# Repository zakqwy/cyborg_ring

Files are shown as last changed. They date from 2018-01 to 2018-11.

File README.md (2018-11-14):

# cyborg ring
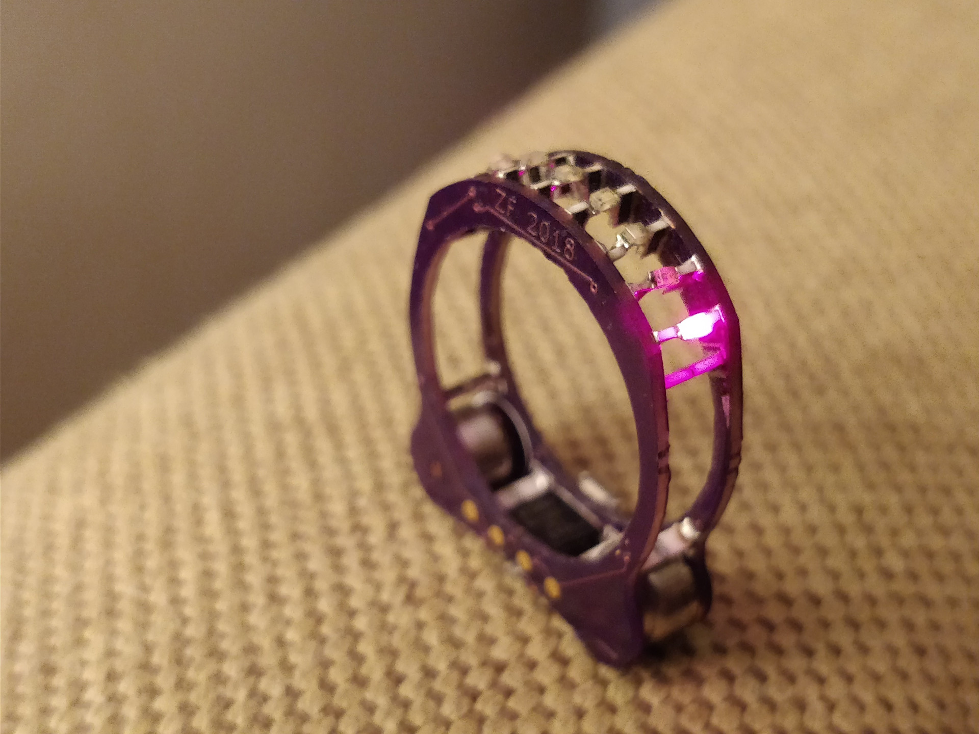
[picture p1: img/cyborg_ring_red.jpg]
cyborg ring with red LEDs

cyborg ring is a cordwood-style bit of blinky jewelry powered by an ATtiny85 and a pair of size 10 Zn-air (hearing aide) batteries. The latest iteration includes several tension wires as well as other minor updates and has proven its durability to be sufficient to warrant a beta release. Note that this ring is difficult to make, still quite delicate, not waterproof (even if you conformal coat most of it), and somewhat uncomfortable. But it's also quite unique.
## license
cyborg ring is released under the terms of the Creative Commons Attribution-ShareAlike 4.0 license, available here: http://creativecommons.org/licenses/by-sa/4.0/.


The project recently received certification from the Open Source Hardware Association, US000141.
OSHWA Certification
## project status
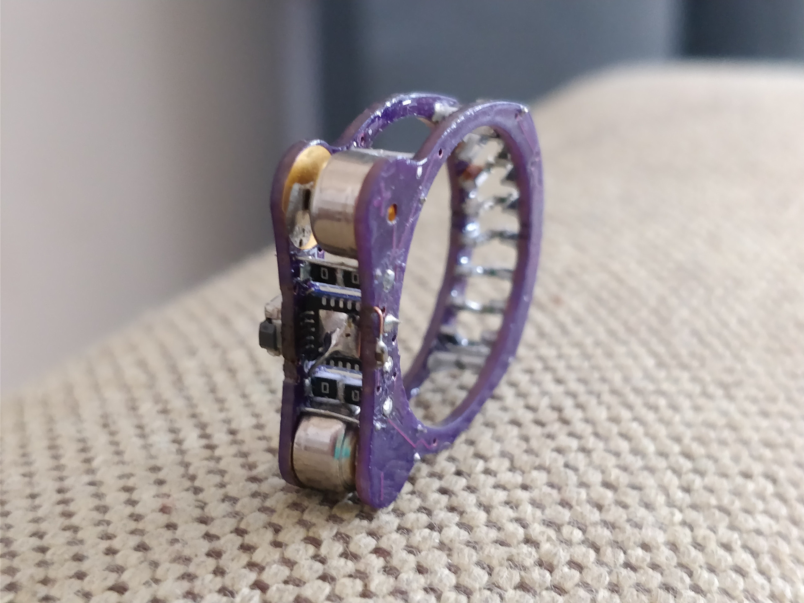
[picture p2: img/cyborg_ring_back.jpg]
cyborg ring rear view

The ring works and seems to last at least a few weeks without breaking; having said that, the ring is still delicate and should be treated like a beta-release concept still in need of some polishing. By popular demand, I'll probably put together a CrowdSupply campaign for kits that will include good instructions, pre-programmed microcontrollers, and LED color / ring size choice. On the subject of size, this version is nominally equivalent to ring size 9. Practically, it's better as a 7 or 8 as the bare FR4 is a bit rough when worn too tight.
## build instructions
I did a live stream in October 2018 that shows a complete ring build start-to-finish. You can view an unedited recording of the stream [here](https://youtu.be/spNg8LhxJz0). I also made a brief video that just goes over the tools and materials, available [here](https://youtu.be/D9dDy7vboAA). These are both great starting points if you are new to the project.
### step zero: prepare thyself
This is a fun and challenging project. Building a ring can be frustrating, especially if you aren't used to working with tiny parts, but if you take your time it is eminently possible even if you are fairly new to soldering. Make sure you are comfortable, not overly caffeinated (as shaky hands make it quite tough), and try to avoid interruptions for the next few hours. Remember that you have extra parts, and even if you damage a PCB the replacements are quite cheap (although they may take a week or two to arrive in the mail).
### step one: source PCBs
Use a service like [OSHpark](https://oshpark.com/shared_projects/sZ3MaKA4) (or any other high-quality PCB vendor) to fabricate the boards. They should be routed with mousebites, 0.8mm (1/32") FR4, ENIG, double-sided. Note that some traces are a bit close to the PCB edge so you may need to try a few services or have your bodge wires handy:
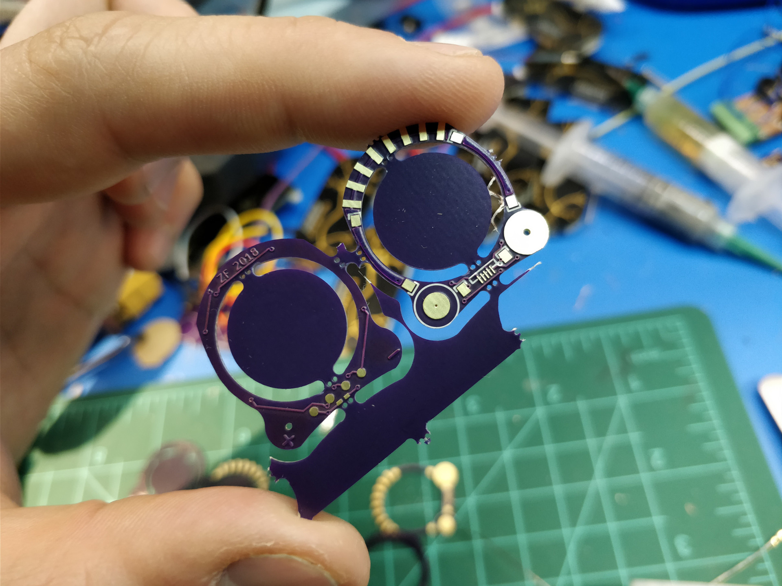
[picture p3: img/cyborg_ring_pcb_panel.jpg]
cyborg ring pcb panel


If necessary, _carefully_ sand down the mouse bites after removing excess FR4. Make sure to wear suitable PPE (safety glasses, a dust mask, etc) and clean up when you are finished:
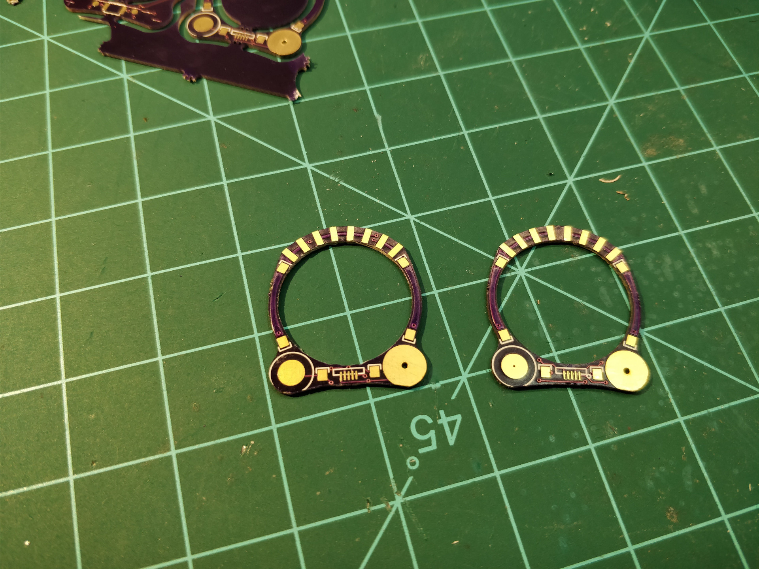
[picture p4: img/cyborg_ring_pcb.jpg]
cyborg ring pcb

### step two: source all the parts
I did a short run of kits that were given away at the 2018 Supercon; if you got one, you already have all you need beyond the tools listed:
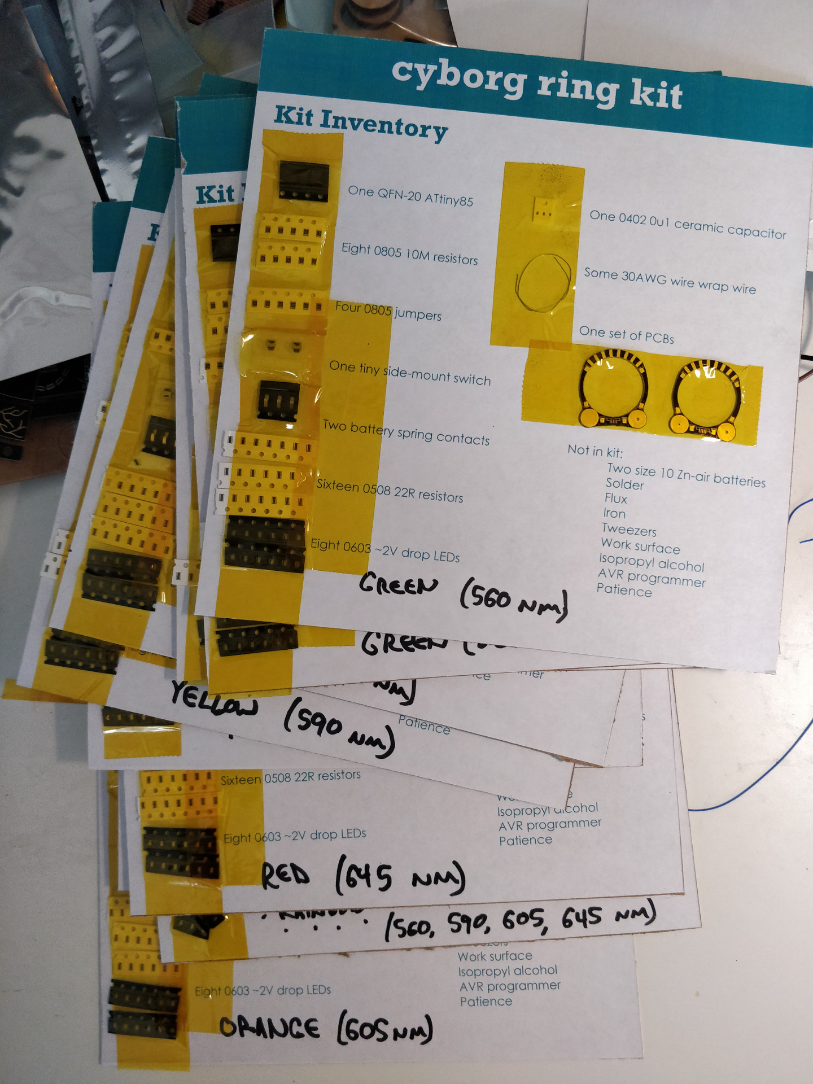
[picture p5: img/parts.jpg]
parts


Otherwise, order the parts listed in bom.csv in the HARDWARE directory. I usually get parts from Digi-Key, but most large electronics distributors should have the parts. Make sure you buy 0508 resistors for the LEDs; they're a bit funky and substantially less common than 0805 devices (which you also need). And don't even _think_ about not ordering sufficient spares of _everything_.
### step three: assemble the resistor columns
You need six columns altogether. Four should be constructed from a pair of 10M 0805 resistors, marked '106', to give a total resistance of 20M. Two should be constructed from a pair of 0805 jumpers, marked '0'. To fabricate the columns, position the two resistors next to each other on a heat-resistant surface (such as a Teflon-jawed Stickvise):
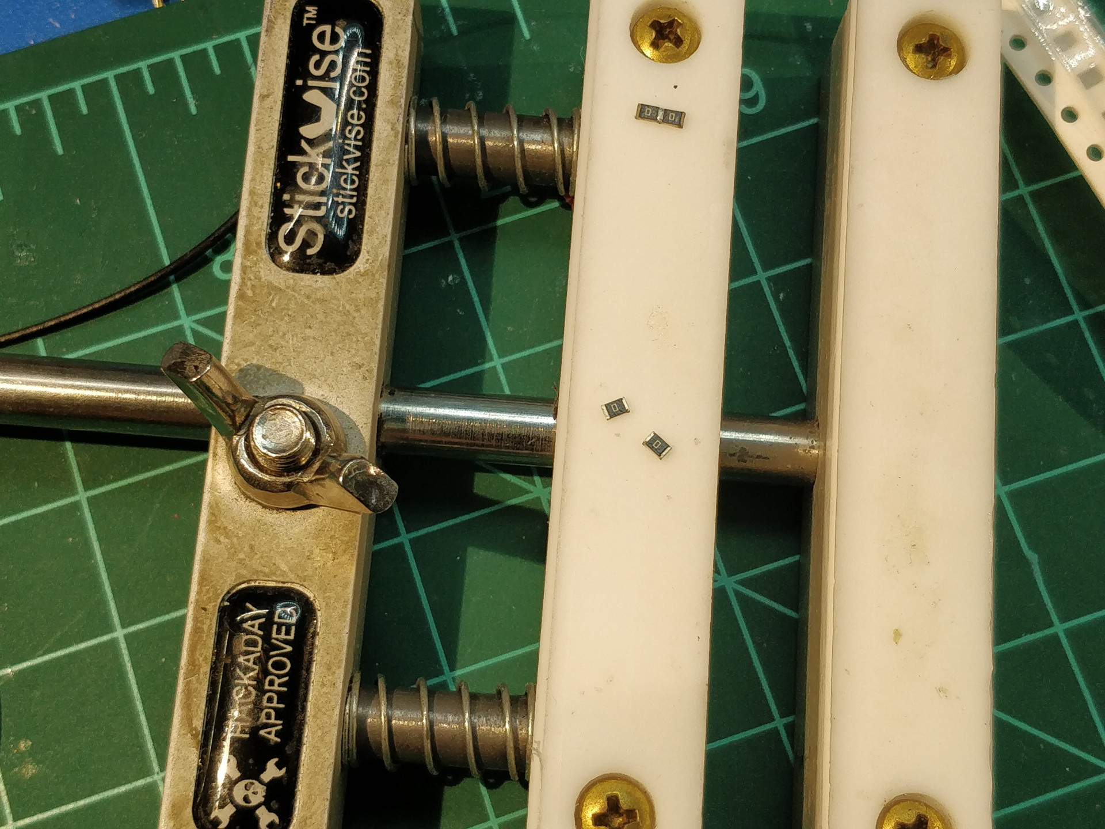
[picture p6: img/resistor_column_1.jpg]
resistor column 1


Squeeze the two resistors together with a pair of tweezers. Make sure they are square to each other and don't squeeze so hard the resistors buckle up in the center; the column should be flat but firmly held:
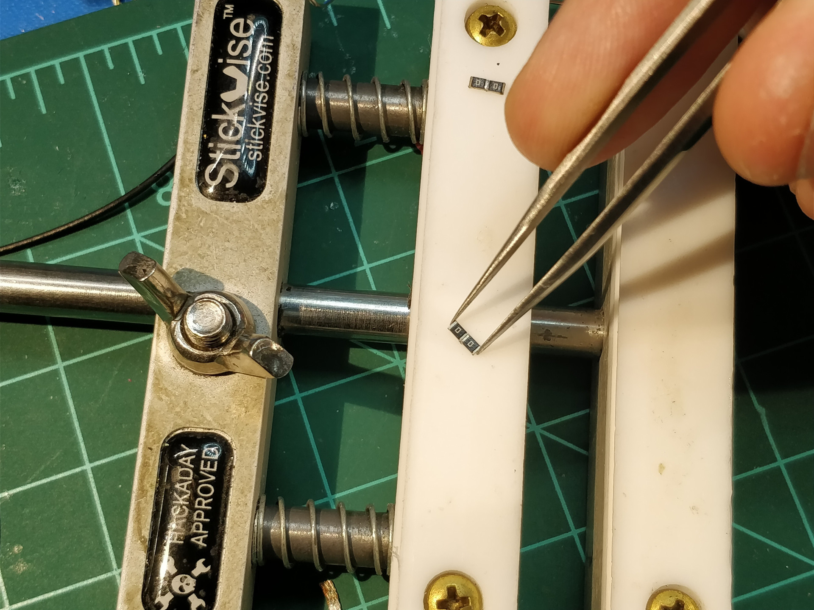
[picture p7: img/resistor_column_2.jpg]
resistor column 2


Apply a bit of gel flux to the junction:
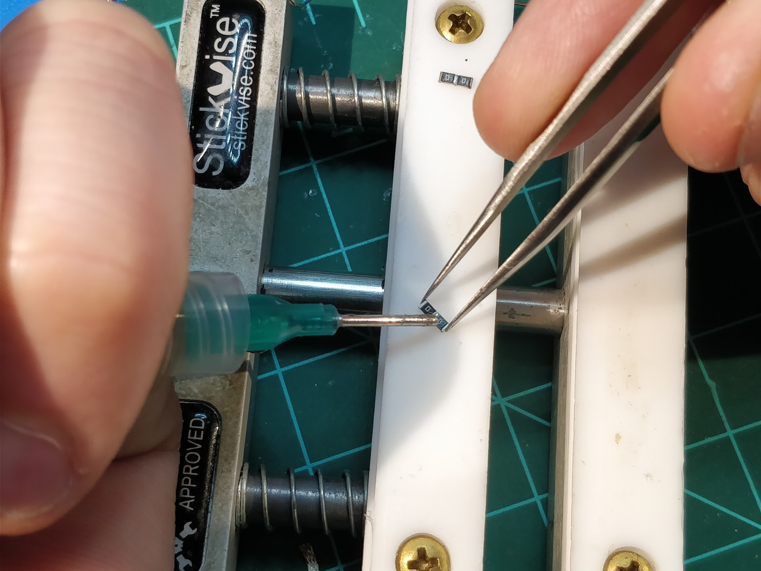
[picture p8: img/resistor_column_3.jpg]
resistor column 3


Touch your tinned soldering iron to the junction, allowing a bit of solder to flow around the joint:
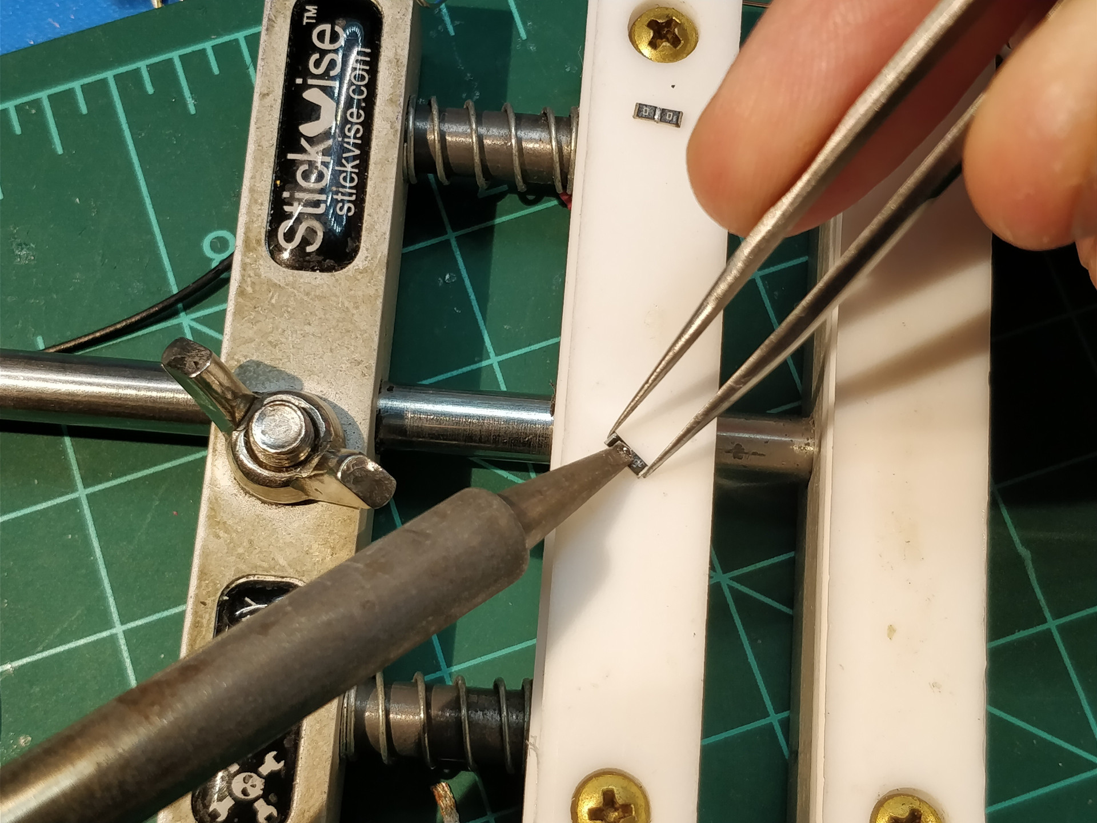
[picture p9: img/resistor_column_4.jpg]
resistor column 4


The finished product should be straight and square, as seen here:
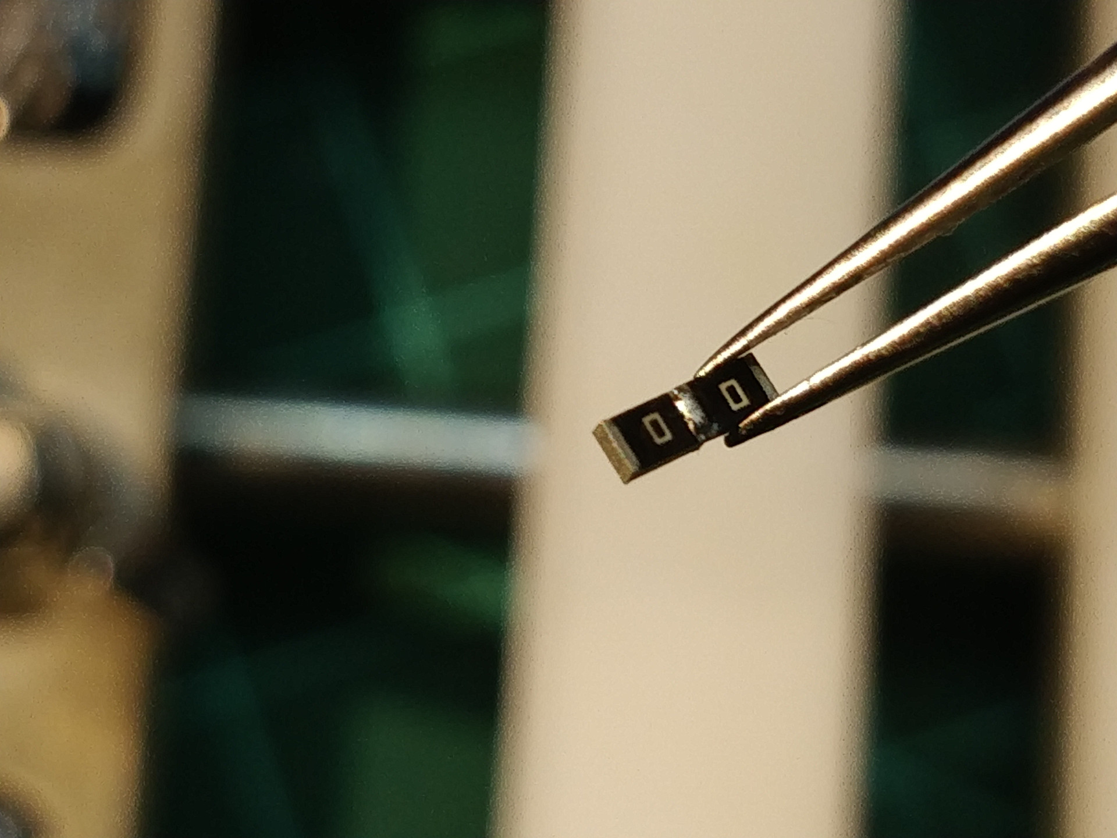
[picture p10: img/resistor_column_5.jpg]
resistor column 5


Repeat as needed until you have two jumper columns and four structural (10M + 10M) columns.
### step four: solder parts to individual ring halves
Identify the bottom half of the ring. This half has two round pads on the back, along with two rectangular pads for the switch. On the front, the ATtiny85 silkscreen has a tiny circle to indicate the location of Pin 1. It also says "cyborg ring" opposite the LEDs:
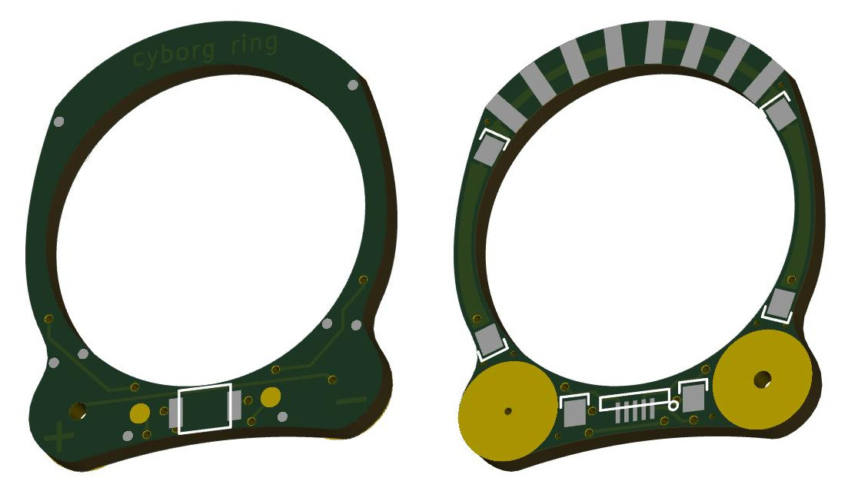
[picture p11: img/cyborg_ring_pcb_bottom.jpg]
cyborg ring pcb bottom


Start by soldering the QFN ATtiny85 to the PCB. You should carefully mount the board in a vise of some kind, or tape it to a work surface (such as an old bit of wood) so it doesn't move around. Use tweezers to orient the QFN so its ground pad faces the bottom part of the ring, and the outline lines up with the white silkscreen square. Be sure the notch on the ground pad, which indicates pin 1, is down and to the right:
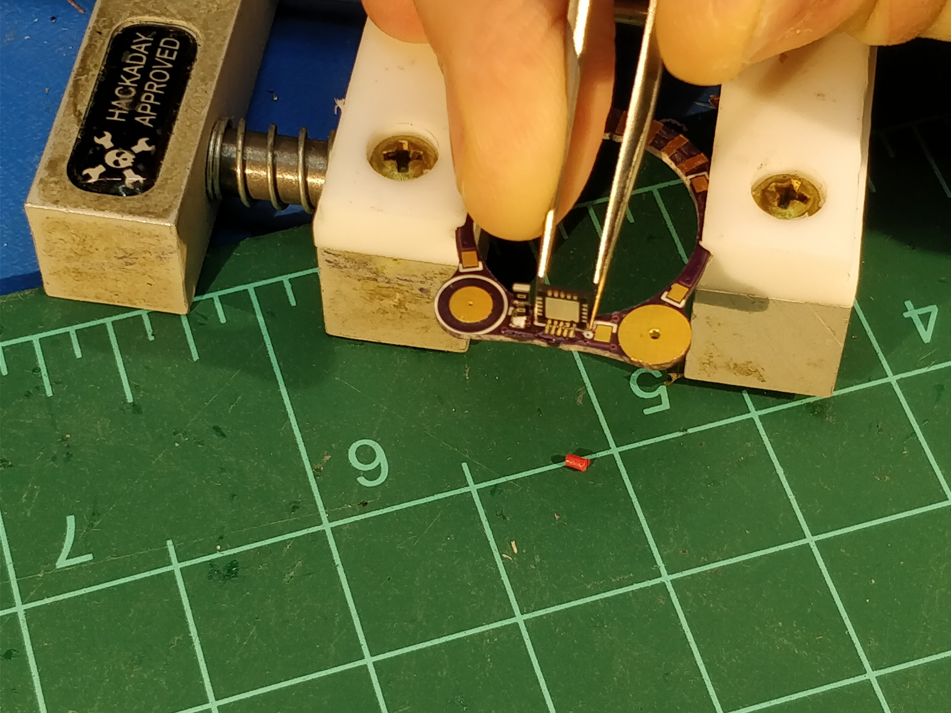
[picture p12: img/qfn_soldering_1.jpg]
qfn soldering 1


Squeeze a healthy blob of gel flux onto the joint (not shown). Tin your soldering iron, keep your tweezers steady, confirm alignment one last time, and slide the iron tip across the joint to flow sufficient solder onto the pads. If you form any bridges, clean off the iron and gently dab it on the pads to remove excess solder:
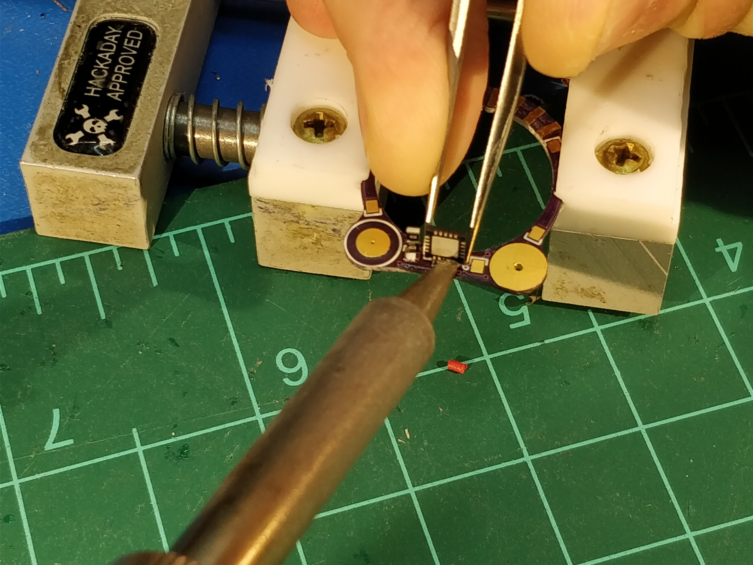
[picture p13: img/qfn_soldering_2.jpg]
qfn soldering 2


The resultant joint should be shiny, convex, aligned front-to-back and side-to-side, and as vertical as you can manage. Examine this joint carefully, ideally with a loupe, and redo if necessary to fix problems:
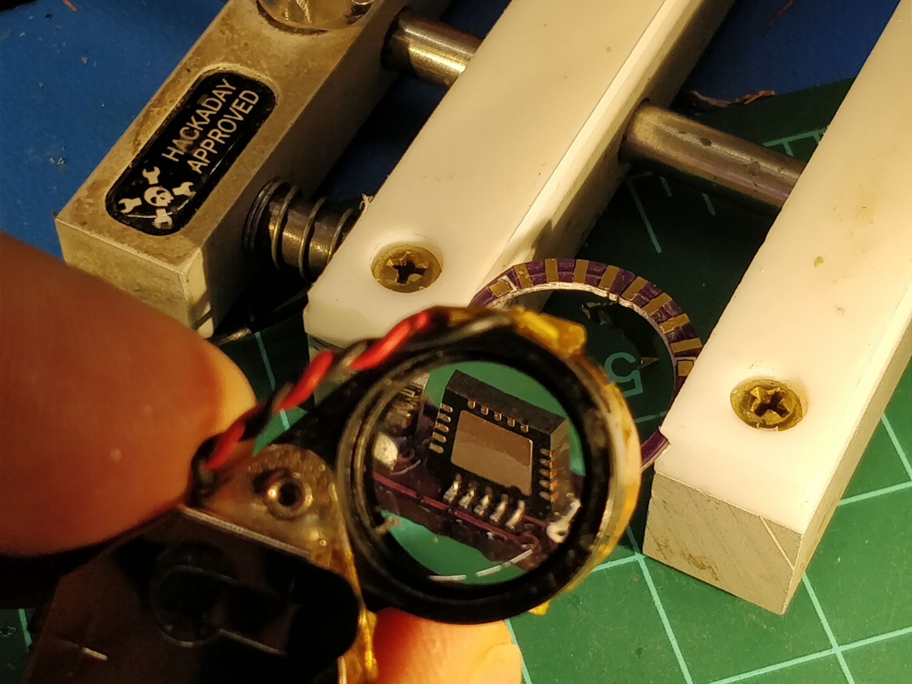
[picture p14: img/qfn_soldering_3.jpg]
qfn soldering 3


Next, solder the six resistor columns to the ring. The two jumper columns guard the QFN, while the four structural columns live near the ring's corners (if round things had corners). Follow the same method as you did with the QFN: add a blob of flux, align the column with tweezers, tin your iron, and touch the hot iron tip to the joint to flow a bit of solder onto the pad and component:
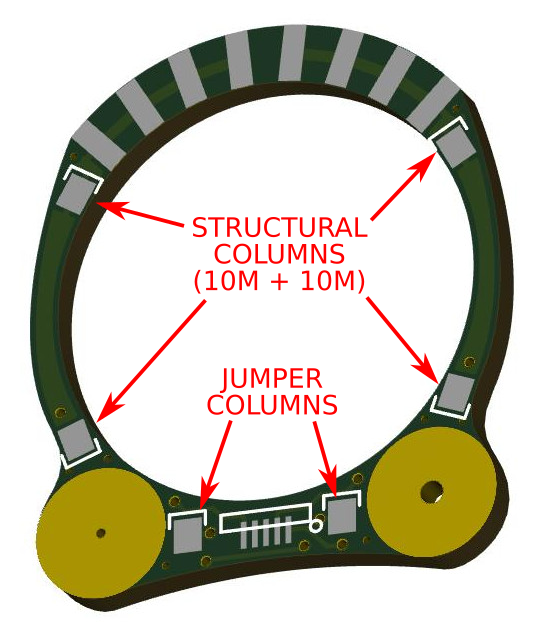
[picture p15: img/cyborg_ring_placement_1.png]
cyborg ring placement 1


Now solder all 0508 resistors to the appropriate pads on the top and bottom of the ring. Orient the resistors so their top edge is flush with the top of the ring. When you are done, the bottom half should look something like this:
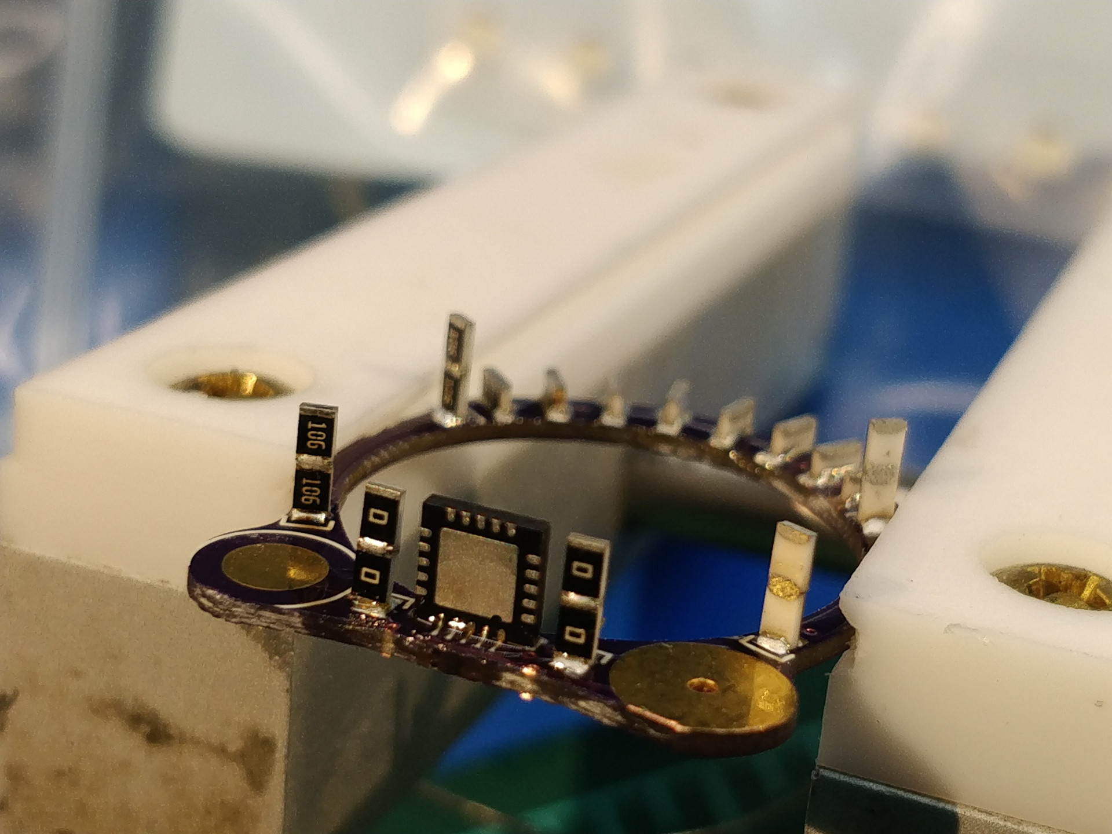
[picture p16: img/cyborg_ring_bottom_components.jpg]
cyborg ring bottom components


Solder the battery tabs to the smaller of the round pads on the left side of each half of the ring. Orient the tabs so the battery can be inserted and removed from the bottom of the ring after assembly. Again, add flux to the pad, align and hold the part, and touch the joint with a tinned iron tip to flow sufficient solder into the joint. Note that the tab in this image is an older version; your parts are sturdier but otherwise similar (and your QFN is straighter than the one in this picture):
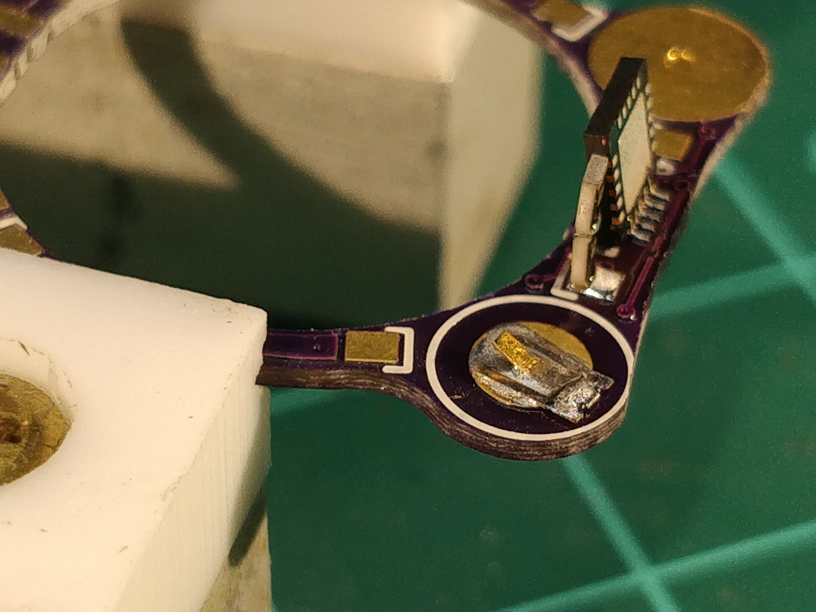
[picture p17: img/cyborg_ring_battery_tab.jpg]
cyborg ring battery tab


### step five: join the two ring halves
This is the most challenging part of the ring construction. The components are all in a delicate state (especially the brittle resistor columns), and the two halves need to be aligned within around 100 microns to ensure the QFN pads all land properly. I demonstrated this step on stage at the 2018 Supercon; [the video](https://www.youtube.com/watch?v=hiBTvdMfvWo) isn't great but hopefully the methodology comes through. I still need to pull together good images showing this part in action, but it's tough to photograph as both hands tend to be busy.

Pick up the bottom ring half (the part with most of the components) with your thumb and forefinger. Place the top ring half over the bottom half, gently squeezing the two PCBs together between your fingers. Adjust your grip so that the two boards are aligned, and ensure that there is some pressure holding them together; any gaps between the components and the PCB will be difficult to fix with solder. As you hold the PCB, notice how much fine control you have over component alignment by sliding your thumb and forefinger relative to each other. Practice getting the QFN pads perfectly in line and holding them that way for a few seconds. Keep an eye on the alignment of the two furthest structural columns; if all three of these joints are in line, the other resistors will fall into place as well.

When you are comfortable with your grip on the PCBs, add a blob of flux to the five unsoldered QFN pads, tin your iron, check alignment one final time, and swipe the iron tip across the pads to flow solder into the joint. Be sure to hold the boards steady during this process; don't let go until the iron has been off the joint for a few seconds, as you must ensure the solder is completely cool or you'll get a cold joint.

As soon as the solder on the QFN joint solidifies, start treating the ring with even greater care. The five pads holding the top PCB are tiny and easily ripped off. Without putting the ring down, add gel flux to the six structural resistor columns, re-tin your iron tip, and touch the six pads in sequence to flow solder into the joints. Now you can put the ring down and inspect your work; the ring is still too delicate to wear (which we will address next), but it shouldn't spontaneously disassemble if left on the workbench until the next morning.
### step six: install reinforcing wires
The major design update between the two hardware revisions to date added eight tension wires. The original ring was incredibly weak in tension or shear, as the resistors would easily lose their solder caps. Think of the columns as un-reinforced concrete: they're pretty decent in compression, but need a bit of help for real-world applications.

Each ring PCB has eight tiny plated holes designed for stripped 30 AWG wire wrap wire. The clearance is tight, so inserting the wire through both holes can be a trial-and-error process. Generally, if you kink or bend the wire in an attempt, you are better off clipping the wire back until you have a fresh straight section to work with. Some of the holes are marked here:
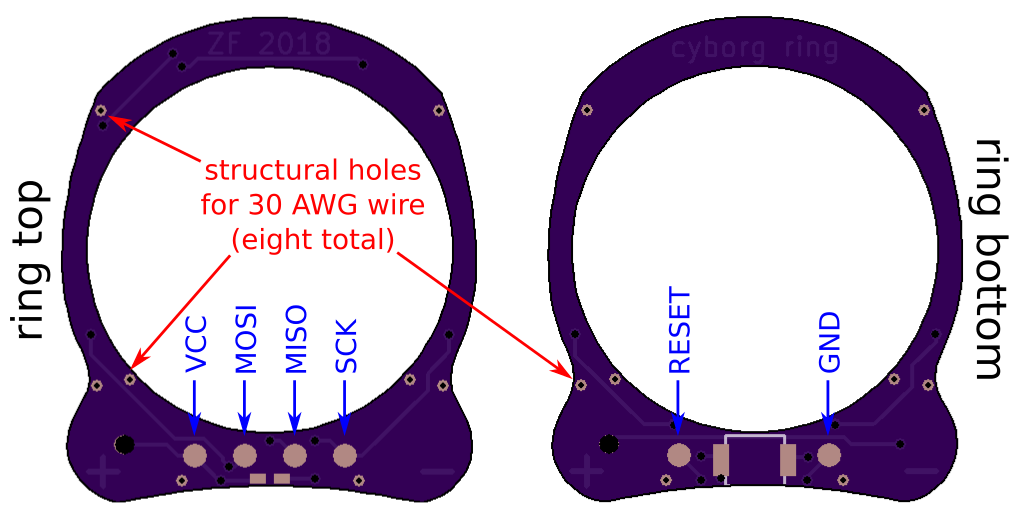
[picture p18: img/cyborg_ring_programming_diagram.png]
cyborg ring programming diagram


One at a time, blob flux onto the wire and holes and apply solder as you did with the other components. As you secure each joint, clip the wires flush. If the clipped wire is sharp, dab it with a tinned iron to add a tiny bit of additional solder to round off the joint.

Now you can wear the ring. But you will probably want to install the rest of the components first, as it's quite a bit more interesting to see when the LEDs work.

### step seven: install the LEDs
The LEDs straddle the gap between the 0508 resistors at the top of each ring PCB. This works because the resistors are 1.2 mm wide each, and 0603 LEDs are 1.6 mm wide. 1.2 + 1.6 + 1.2 = 4, and it means the LEDs are nicely centered. However, they are quite delicate and dependent on nominal tolerances, so they don't always fit quite right, and can easily break if you throw an unprotected ring in your backpack for a month (as I did on the broken-but-re-LED-able ring shown on the right here):
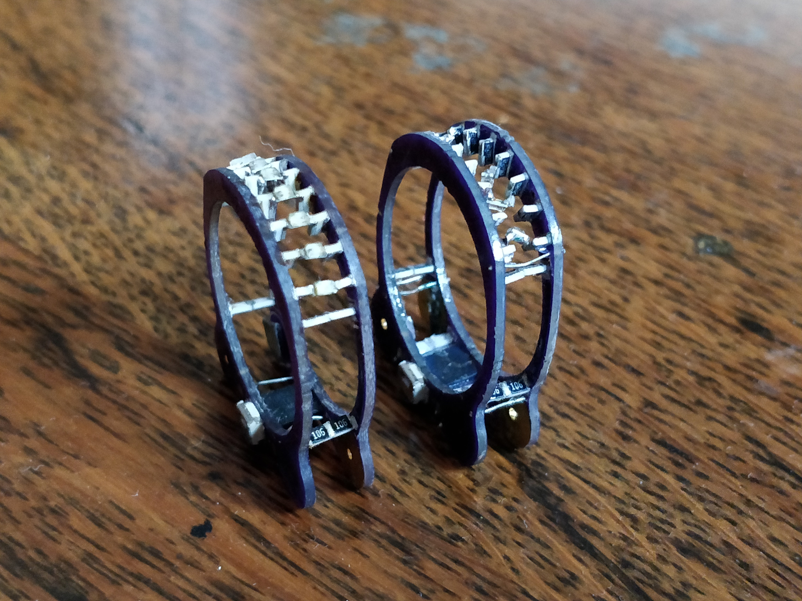
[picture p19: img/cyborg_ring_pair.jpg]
cyborg ring pair


LED polarity should always be confirmed on the LED datasheet, but in most cases the cathode (negative) terminal of a component can be identified by the black dot visible through the epoxy package. Install the LEDs according to this diagram:
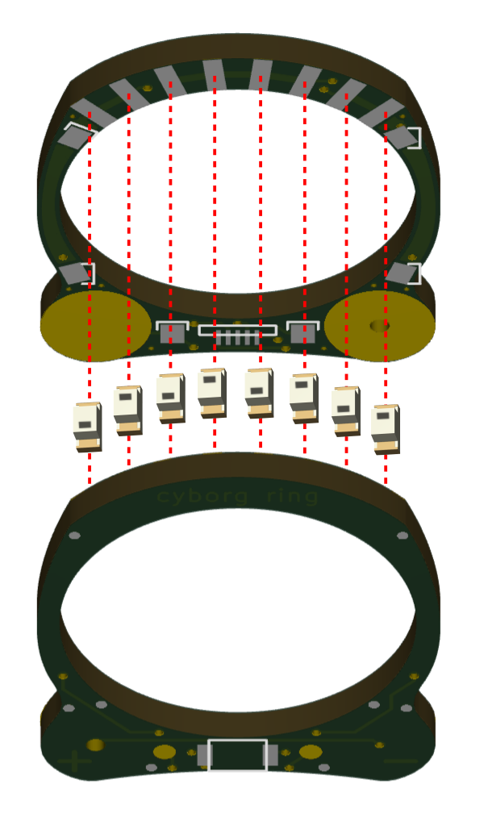
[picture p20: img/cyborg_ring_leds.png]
cyborg ring leds


Don't worry if you get all of them backwards. The LEDs are Charlieplexed, so they will still light up but will be in a funky order. You can fix them, or you can fix the code. Just make sure the polarities alternate from one to the next.

Secure the ring upright. To install the LEDs, dab a bit of gel flux on the free pads of the 0508 resistors and the LED terminals. Hold each LED in sequence in its appropriate place and touch your tinned iron to the terminal to flow solder into the joint. This may take a bit of practice and rework, so take your time. Be sure to solder both sides of each LED before you move on to the next.
### step eight: final components and ground jumper
The ring has two components that must be soldered in traditional fashion to the PCBs. The 0402 bypass capacitor should be soldered to the top PCB, while the side-mounted switch should be soldered to the bottom PCB. The switch pads aren't terribly generous, so a good strategy is to tin the pads and switch terminals, deflux the whole ring with isopropyl alcohol (as the switch isn't sealed), and secure the switch by reflowing the pads from above.

Remember how the QFN ATtiny85 (/45/25) is great for cordwood because all of the pins are broken out on two sides of the QFN? Well .. not _quite_ all of the pins. You have to jumper in the ground connection. To do this, blob some flux onto the ground pad on the back of the chip and touch it with a tinned iron to flow on some solder. Then, tack a fluxed length of wire wrap wire onto the blob, being careful to avoid shorting the wire against any pins. Solder the other end of the wire to the resistor jumper column _opposite_ the ATtiny's Pin 1 indicator, as shown here:
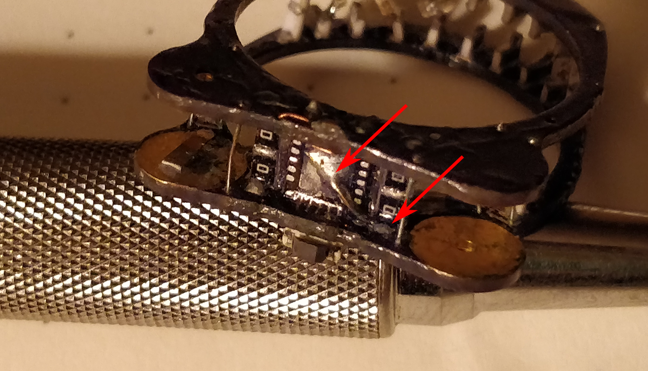
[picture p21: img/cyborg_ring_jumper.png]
cyborg ring jummper


You can also use the position of the switch as a guide, following the image above.
### step nine: programming
The ring firmware (/FIRMWARE) runs on an ATtiny85 microcontroller, but can easily work with a -25 or -45 as well (these devices simply have less flash memory, not a problem for our tiny program). If you use an ATtiny25 or ATtiny45, be sure to change the DEVICE line of the Makefile as required.

You can program the ring with any suitable AVR programmer: a USBtinyISP, an Arduino, or one of Atmel's many official devices. Using these specific devices is outside the scope of these instructions; a good starting point is Adafruit's fantastic guide for their USBtinyISP, available [here](https://learn.adafruit.com/usbtinyisp). Connect your programmer of choice to the following pads on the ring:
cyborg ring programming diagram

The pads are 0.1" spaced so you _can_ build a clever pinchy programmer rig out of perfboard and pogo pins, like this:
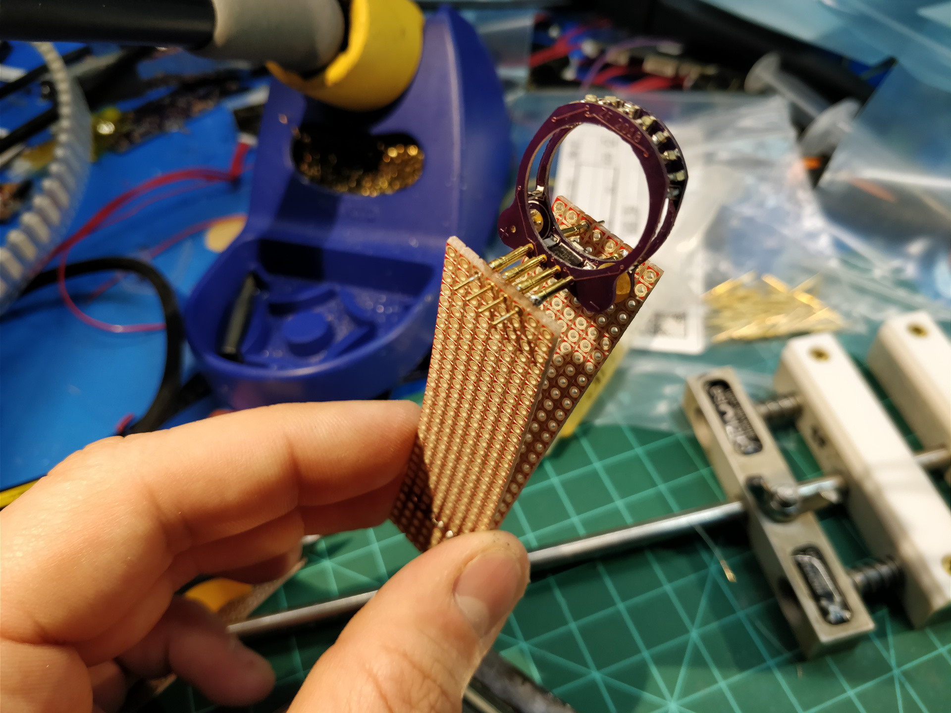
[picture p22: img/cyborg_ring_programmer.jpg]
cyborg ring programmer


The programming rig works well enough, but it's fussy to get aligned so I usually just tack wires onto the pads. The current firmware zips the LEDs sequentially three times, then puts the microcontroller to sleep. Battery life should be in the 6-8 weeks range and is probably chemistry-limited rather than related to current draw (unless you play with the ring _constantly_)

Optionally, you can now coat the exposed parts of the ring with silicone modified conformal coating. The ring won't be waterproof, but it will be a bit better protected.

cyborg ring gif
### step ten: what to do if your ring doesn't work
I have built five of these rings as of November 2018, and I had to perform at least some rework on three of them before they would accept a program. So don't fret if you get an avrdude error! A few recommended troubleshooting steps:
* Double-check the programming connections against the diagram shown in step 9. While you're at it, make sure your programmer is connected and working (and providing power, if you haven't installed batteries yet)!
* Make sure the ATtiny is oriented correctly vs the pin 1 indicator. Seriously, I messed this up _several times_ but was able to recover using hot air in all cases.
* Re-examine the QFN solder joints with a loupe. If the chip is lifted or misaligned at all, one or more of the fillets may not contact the pads and it's really tough to see without 10x or better magnification. If you see some suspect solder joints, clean them with a bit of isopropyl alcohol, add flux, and gently sweep them with a lightly tinned iron tip.
* Make sure you didn't swap the resistor columns! The two on either side of the ATtiny should be jumpers, while the other four should be 10M + 10M.

Finally, please don't hesitate to get in touch if you want a second set of eyes on your work. The best route to contact me for help with your build is via [Twitter](https://twitter.com/zakqwy). If you aren't on that platform, you can also submit a GitHub Issue. Make sure to include close-up pictures!
## known builds
Building a cyborg ring and willing to share your process? Send me a link and I'll add it here.

[F0cks' build](https://blog.f0cks.net/projects/Cyborg-ring/), remixed to ring size 6.5-7 in Eagle and used for a proposal!

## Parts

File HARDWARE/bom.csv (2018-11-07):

Part Name (REF) | Qty | Value | Link | Mfr | Mfr Part # | Package | RoHS | Subs Allowed
Battery spring contacts (BOT_PAD1 TOP_PAD2 ) | 2 | BATT0- BATT1- | https://www.digikey.com/product-detail/en/te-connectivity-amp-connectors/1447360-8/A108284CT-ND/4022011 | TE Connectivity | 1447360-8 | SMT | Yes | No
Jumper columns, 0805x2 (BOT_R2 TOP_R2 TOP_R1 BOT_R1) | 4 | JMP | any |  |  | R0805+R0805 | Yes | Yes
Structural columns, 0805x2 (BOT_R6 TOP_R6 BOT_R5 TOP_R5 BOT_R4 TOP_R4 TOP_R3 BOT_R3) | 8 | 10M | any |  |  | R0805+R0805 | Yes | Yes
Microcontroller (BOT_U1 TOP_U1) | 1 | ATtiny85_QFN20_1-5 | https://www.digikey.com/product-detail/en/microchip-technology/ATTINY85-20MUR/ATTINY85-20MURCT-ND/2774367 | Atmel/Microchip | ATTINY85-20MUR | QFN20-0.5 | Yes | No
Bypass capacitor (C1) | 1 | 0u1 | any |  |  | C0402 | Yes | Yes
Pushbutton switch, side-mounted, tiny (SW1) | 1 | SW_PUSH | https://www.digikey.com/product-detail/en/omron-electronics-inc-emc-div/B3U-3000P/SW1022CT-ND/1534359 | Omron Electronics | B3U-3000P | SMT | Yes | No
LEDs, 0603, 2 V drop, 650 – 565 nm (TOP_D1 BOT_D1 BOT_D2 TOP_D2 TOP_D3 BOT_D3 BOT_D4 TOP_D4 TOP_D5 BOT_D5 BOT_D6 TOP_D6 TOP_D7 BOT_D7 BOT_D8 TOP_D8) | 8 | LED | any |  |  | LED0603 | Yes | Yes
Resistors for LEDs, 0508 | 16 | 22R | https://www.digikey.com/product-detail/en/rohm-semiconductor/LTR10EZPF22R0/RHM1211CT-ND/4055428 | Rohm Semiconductor | LTR10EZPF22R0 | R0508 | Yes | No
BOM made with KICAD_BOM_WIZARD (https://github.com/HashDefineElectronics/KiCad_BOM_Wizard.git)
Generated Thu 24 May 2018 09:12:32 AM CDT

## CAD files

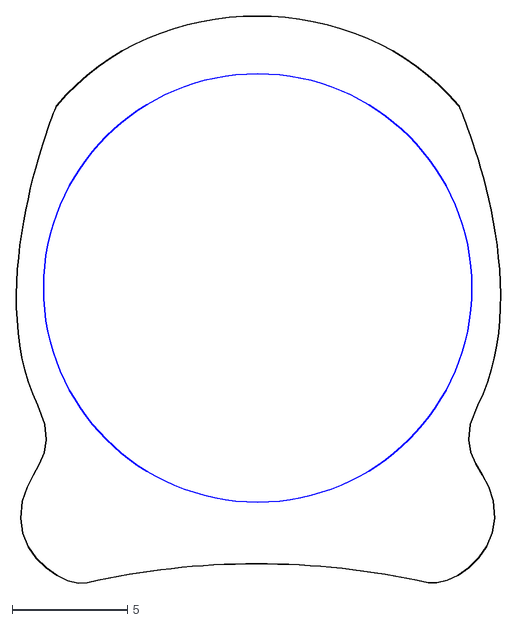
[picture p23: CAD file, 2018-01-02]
HARDWARE/cyborg_ring.dxf
21.0 x 24.6

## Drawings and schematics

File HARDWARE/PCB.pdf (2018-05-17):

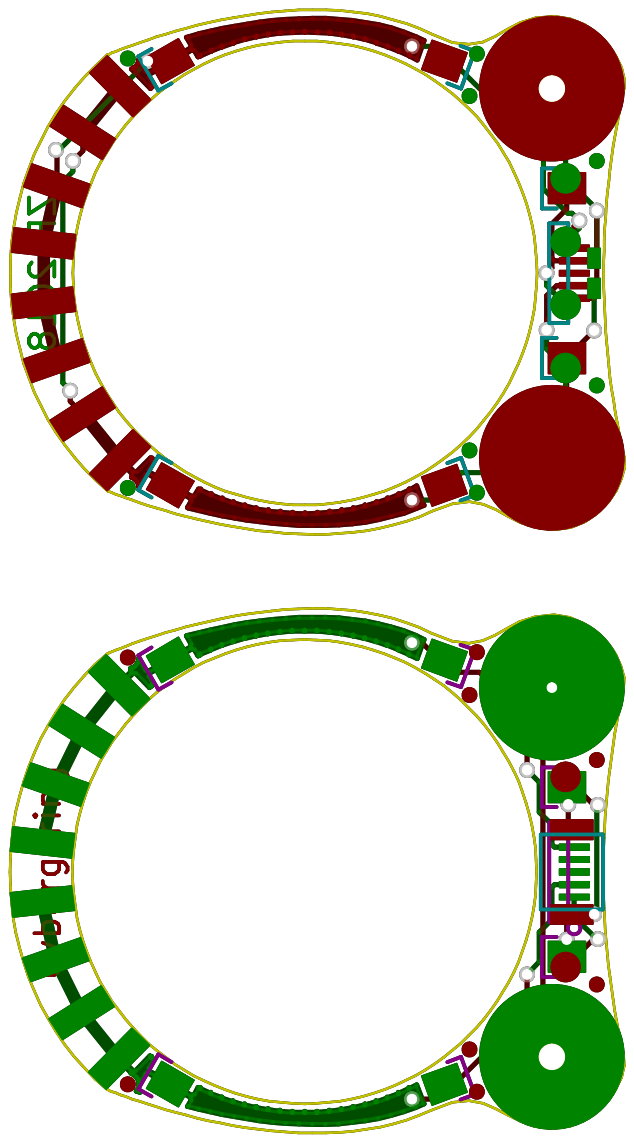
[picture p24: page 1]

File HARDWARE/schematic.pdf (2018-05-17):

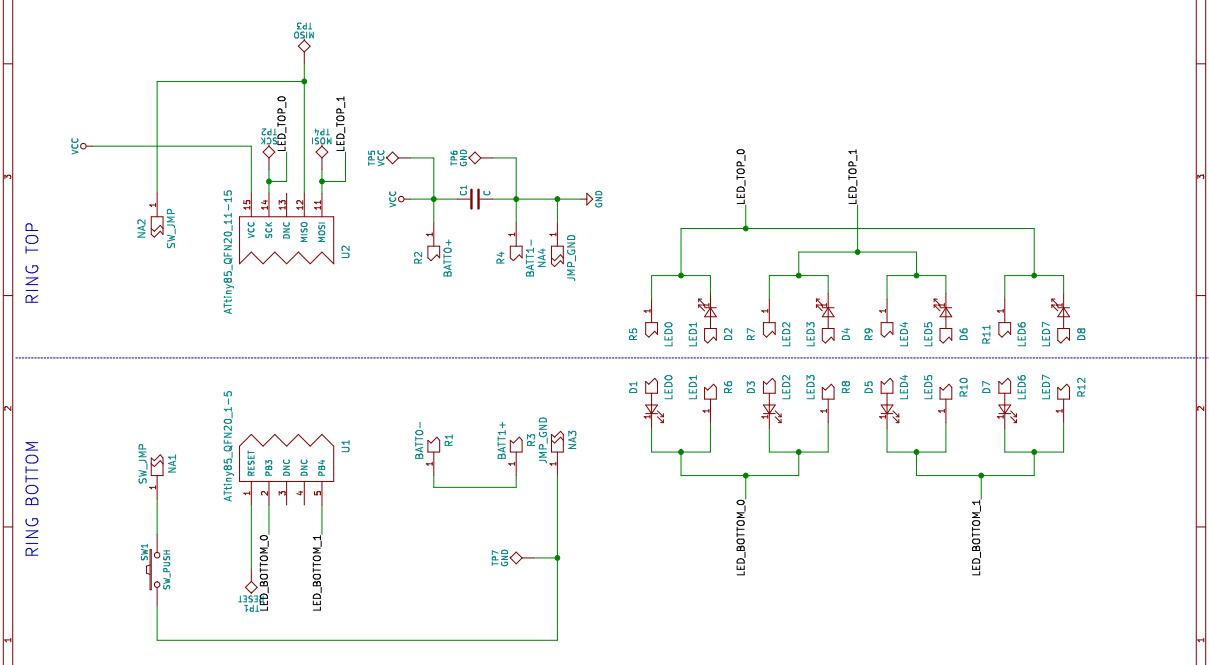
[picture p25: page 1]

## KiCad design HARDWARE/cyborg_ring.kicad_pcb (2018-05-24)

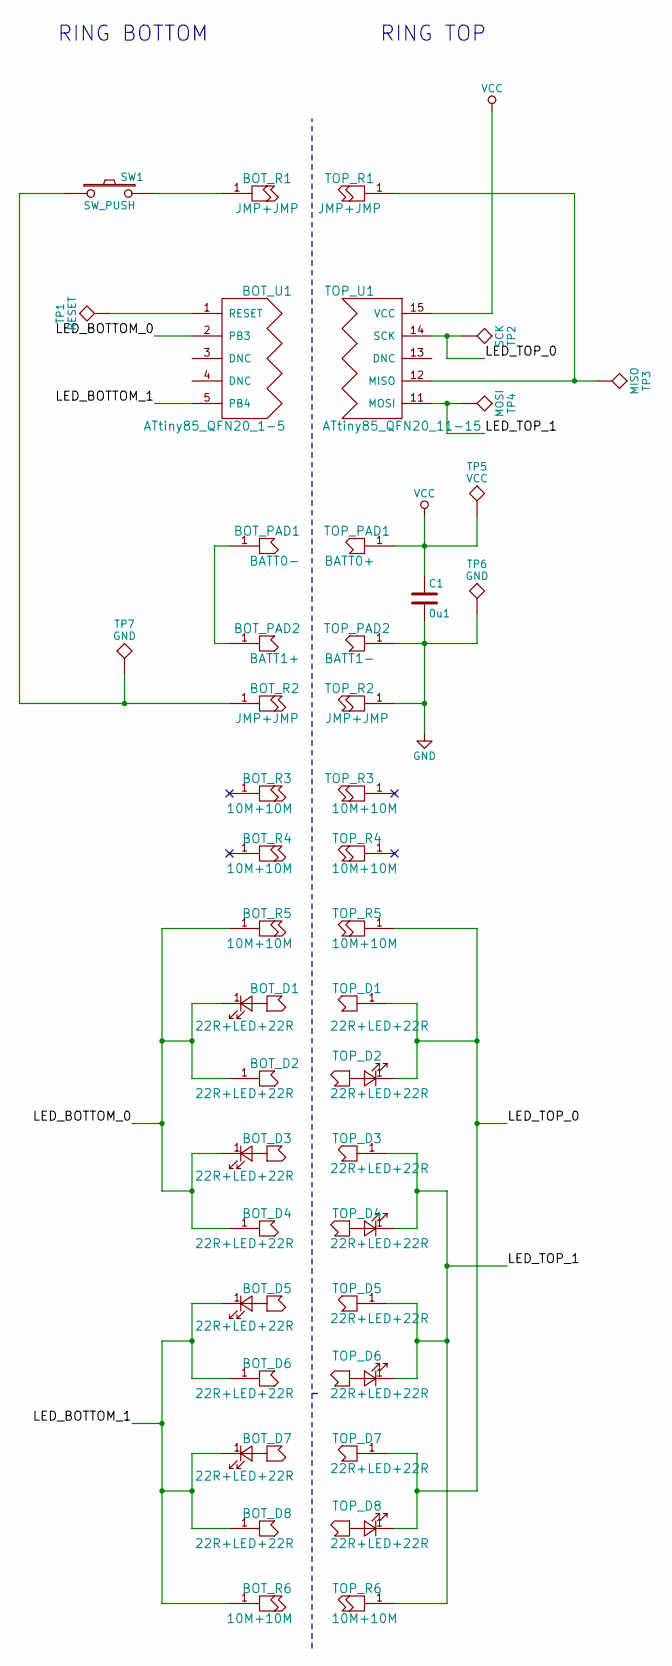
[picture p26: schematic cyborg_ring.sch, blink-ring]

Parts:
BOT_D1, BOT_D2, BOT_D3, BOT_D4, BOT_D5, BOT_D6, BOT_D7, BOT_D8: 22R+LED+22R; ZF_SMD_0508_CORD
BOT_PAD1: BATT0-; ZF_BATT_AC10E_NEG; Mfr Part # 1447360-8
BOT_PAD2: BATT1+; ZF_BATT_AC10E_POS
BOT_R1, BOT_R2: JMP+JMP; ZF_SMD_0805_CORD
BOT_R3, BOT_R4, BOT_R5, BOT_R6: 10M+10M; ZF_SMD_0805_CORD
BOT_U1: ATtiny85_QFN20_1-5; ZF_IC_MLF20-050_CORD_1-5; Mfr Part # ATTINY85-20MUR
C1: 0u1; ZF_SMD_NonPol_0402_cap
SW1: SW_PUSH; ZF_SW_B3U; Mfr Part # B3U-3000P
TOP_D1, TOP_D2, TOP_D3, TOP_D4, TOP_D5, TOP_D6, TOP_D7, TOP_D8: 22R+LED+22R; ZF_SMD_0508_CORD
TOP_PAD1: BATT0+; ZF_BATT_AC10E_POS
TOP_PAD2: BATT1-; ZF_BATT_AC10E_NEG; Mfr Part # 1447360-8
TOP_R1, TOP_R2: JMP+JMP; ZF_SMD_0805_CORD
TOP_R3, TOP_R4, TOP_R5, TOP_R6: 10M+10M; ZF_SMD_0805_CORD
TOP_U1: ATtiny85_QFN20_11-15; ZF_IC_MLF20-050_CORD_11-15; Mfr Part # ATTINY85-20MUR
TP1: RESET; ZF_CONN_1-2_pad
TP2: SCK; ZF_CONN_1-2_pad
TP3: MISO; ZF_CONN_1-2_pad
TP4: MOSI; ZF_CONN_1-2_pad
TP5: VCC; ZF_CONN_1-2_pad
TP6, TP7: GND; ZF_CONN_1-2_pad

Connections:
/LED_BOTTOM_0: BOT_D1.1, BOT_D2.1, BOT_D3.1, BOT_D4.1, BOT_R5.1, BOT_U1.2 (PB3)
/LED_BOTTOM_1: BOT_D5.1, BOT_D6.1, BOT_D7.1, BOT_D8.1, BOT_R6.1, BOT_U1.5 (PB4)
/LED_TOP_0: TOP_D1.1, TOP_D2.1, TOP_D7.1, TOP_D8.1, TOP_R5.1, TOP_U1.14 (SCK), TP2.1
/LED_TOP_1: TOP_D3.1, TOP_D4.1, TOP_D5.1, TOP_D6.1, TOP_R6.1, TOP_U1.11 (MOSI), TP4.1
GND: C1.2, TOP_PAD2.1, TOP_R2.1, TP6.1
unnamed: BOT_PAD1.1, BOT_PAD2.1
unnamed: BOT_R1.1, SW1.2
unnamed: BOT_R2.1, SW1.1, TP7.1
unnamed: BOT_U1.1 (RESET), TP1.1
unnamed: TOP_R1.1, TOP_U1.12 (MISO), TP3.1
VCC: C1.1, TOP_PAD1.1, TOP_U1.15 (VCC), TP5.1

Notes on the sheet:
RING BOTTOM
RING TOP

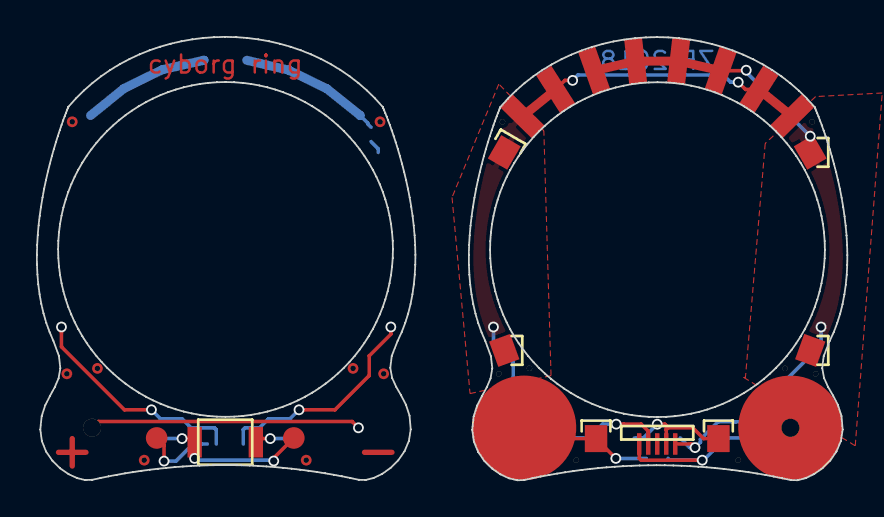
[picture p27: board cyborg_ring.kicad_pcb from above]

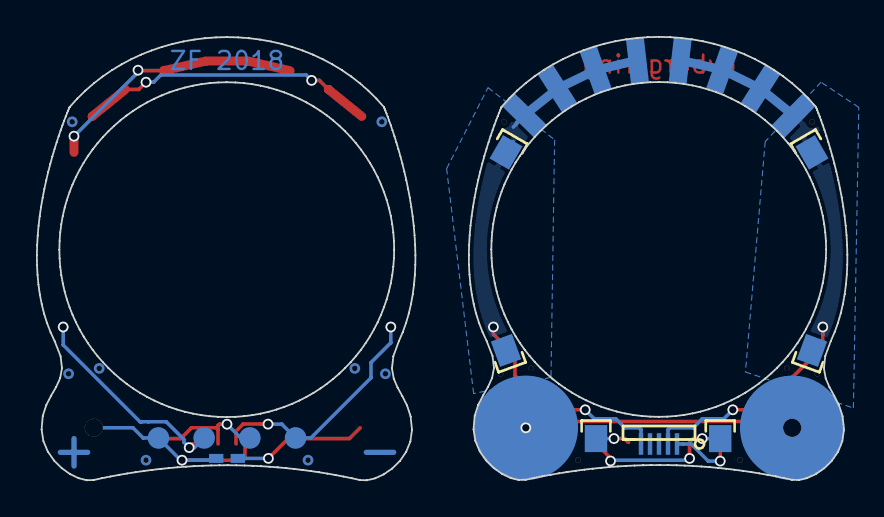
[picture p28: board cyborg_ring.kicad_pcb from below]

Board: 2 copper layers, 45.0 x 24.6 mm, 42 parts (22 on the bottom side), 11 nets.

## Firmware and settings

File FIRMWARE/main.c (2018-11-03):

#include <avr/io.h>
#include <avr/interrupt.h>
#include <avr/sleep.h>
#include "HAL.h"

volatile uint8_t tick = 0;
uint8_t direction = 1; //1 = pos, 0 = neg
uint8_t count = 0;
uint8_t count_reset = 3;
uint8_t currentLED = 0;

ISR(TIM0_COMPA_vect) {
	tick = 1;
}

ISR(PCINT0_vect) {
	count = 0;
	currentLED = 0;
}

int main(void) {
	SystemInit();
	uint8_t currentLED = 0;

	for(;;) {
		while(tick == 0) {} //idle until Timer0 compare match interrupt
		tick = 0;

		illuminateLED(currentLED);

		if (direction == 1) {
			currentLED++;
		}
		else {
			currentLED--;
		}

		if (currentLED == 50) {
			direction = 0;
			count++;
		}
		if (currentLED == 0) {
			direction = 1;
		}

		if (count == count_reset) {
			set_sleep_mode(SLEEP_MODE_PWR_DOWN);
			sleep_enable();
			sleep_cpu();
		}
	}
}	

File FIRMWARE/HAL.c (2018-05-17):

/* 

Released under the terms of the MIT License.

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
The above copyright notice and this permission notice shall be included in all copies or substantial portions of the Software.

THE SOFTWARE IS PROVIDED "AS IS", WITHOUT WARRANTY OF ANY KIND, EXPRESS OR IMPLIED, INCLUDING BUT NOT LIMITED TO THE WARRANTIES OF MERCHANTABILITY, FITNESS FOR A PARTICULAR PURPOSE AND NONINFRINGEMENT. IN NO EVENT SHALL THE AUTHORS OR COPYRIGHT HOLDERS BE LIABLE FOR ANY CLAIM, DAMAGES OR OTHER LIABILITY, WHETHER IN AN ACTION OF CONTRACT, TORT OR OTHERWISE, ARISING FROM, OUT OF OR IN CONNECTION WITH THE SOFTWARE OR THE USE OR OTHER DEALINGS IN THE SOFTWARE.	

Charlieplexing!

PB3		LED_BOTTOM_0
PB4		LED_BOTTOM_1
PB2		LED_TOP_0
PB0		LED_TOP_1
PB1		Switch (pull up)

					  |----|<D0----|
				 |----|			   |--------------------|	
				 |	  |----D1>|----|					|
LED_BOTTOM_0 ----|										|----LED_TOP_0
				 |    |----|<D2----|	 				|
				 |----|			   |----|				|
					  |----D3>|----|	|		 		|
										|				|
										|----LED_TOP_1	|
										|				|
					  |----|<D4----|	|				|
				 |----|			   |----|				|
				 |	  |----D5>|----|					|
LED_BOTTOM_1 ----|										|
				 |    |----|<D6----|		 			|
				 |----|			   |--------------------|	 
					  |----D7>|----|		 





*/

#include <avr/io.h>
#include <avr/interrupt.h>
#include "HAL.h"

void SystemInit(void) {
	DDRB = 0; //set everything to an input for now
	PORTB |= (1<<PB1); //switch pullup

	// set up tick timer:
	TCCR0A |= (1<<WGM01); //CTC at OCR0A
	TCCR0B |= ((1<<CS02) | (1<<CS00)); //clk/1024
	OCR0A = 30; //sets tick to ~1ms
	TIMSK |= (1<<OCIE0A); //output compare match 0A interrupt enable
	GIMSK |= (1<<PCIE); //pin change interrupt enable
	PCMSK |= (1<<PCINT1);
	sei();
}

void illuminateLED(uint8_t LED) {
	//	PB3		LED_BOTTOM_0
	//	PB4		LED_BOTTOM_1
	//	PB2		LED_TOP_0
	//	PB0		LED_TOP_1

	DDRB = 0;
	PORTB &= ~((1<<PB0) | (1<<PB2) | (1<<PB3) | (1<<PB4));
	switch(LED) {
		case 0:
			DDRB |= ((1<<PB3) | (1<<PB2));
			PORTB &= ~(1<<PB2);
			PORTB |= (1<<PB3);
			break;
			
		case 1:
			DDRB |= ((1<<PB3) | (1<<PB2));
			PORTB &= ~(1<<PB3);
			PORTB |= (1<<PB2);
			break;

		case 2:
			DDRB |= ((1<<PB3) | (1<<PB0));
			PORTB |= (1<<PB3);
			PORTB &= ~(1<<PB0);
			break;

		case 3:
			DDRB |= ((1<<PB3) | (1<<PB0));
			PORTB &= ~(1<<PB3);
			PORTB |= (1<<PB0);
			break;

		case 4:
			DDRB |= ((1<<PB4) | (1<<PB0));
			PORTB |= (1<<PB4);
			PORTB &= ~(1<<PB0);
			break;

		case 5:
			DDRB |= ((1<<PB4) | (1<<PB0));
			PORTB &= ~(1<<PB4);
			PORTB |= (1<<PB0);
			break;
	
		case 6:
			DDRB |= ((1<<PB4) | (1<<PB2));
			PORTB &= ~(1<<PB2);
			PORTB |= (1<<PB4);
			break;

		case 7:
			DDRB |= ((1<<PB4) | (1<<PB2));
			PORTB |= (1<<PB2);
			PORTB &= ~(1<<PB4);
			break;
	}
}

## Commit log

2017-12-26 initial commit. first rev schematic, start of pcb.
    [blink-ring.kicad_pcb, blink-ring.sch]
2018-01-02 finalized PCB outline and layout. ordered first rev.
    [blink-ring.dxf, blink-ring.kicad_pcb, blink-ring.sch]
2018-01-15 assembled board and bodged together some demo firmware. needs a few pcb tweaks but everything works..
    [HAL.c, main.c]
2018-02-02 new PCB rev. added reinforcements, changed battery contact, fixed open LED trace
    [blink-ring.kicad_pcb]
2018-05-17 localized schematic symbols. changed name. minor formatting changes.
    [cyborg_ring-B.Cu.gbr, cyborg_ring-B.Mask.gbr, cyborg_ring-B.SilkS.gbr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]
2018-05-17 updated bom.csv. minor README.md updates. added a few images.
    [bom.csv]
2018-05-24 added 10M+10M R0805+R0805 reinforcement resistors to BOM and schematic. updated component references on schematic, BOM, and layout to start with 'BOT_' or 'TOP_' for cordwood-style installations. min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
    [bom.csv, cyborg_ring.kicad_pcb, cyborg_ring.sch]
2018-11-07 documentation updates
    [bom.csv]
2018-11-14 added ground jumper diagram and instructions. added 'what to do if your ring doesn't work' section.

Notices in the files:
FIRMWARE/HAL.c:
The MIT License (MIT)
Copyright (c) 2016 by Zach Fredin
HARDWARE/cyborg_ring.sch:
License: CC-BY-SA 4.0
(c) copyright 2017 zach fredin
